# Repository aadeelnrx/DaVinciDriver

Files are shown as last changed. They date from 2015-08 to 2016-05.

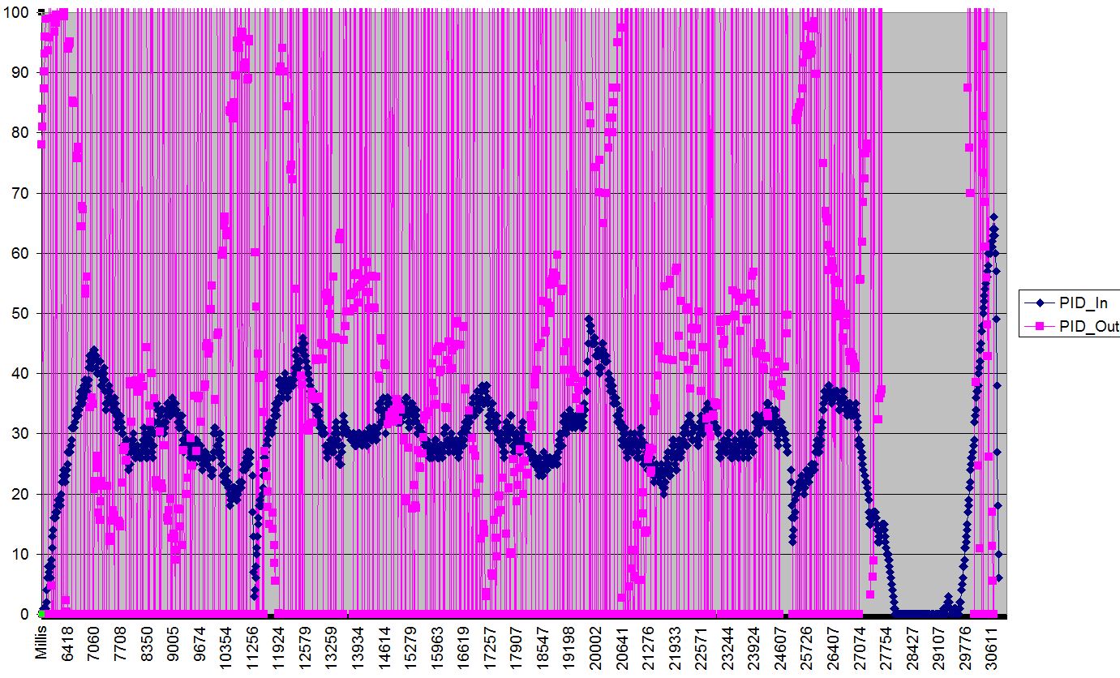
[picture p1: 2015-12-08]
doc/Misc/PID_Measurements/CapturePID_25_10_1.JPG

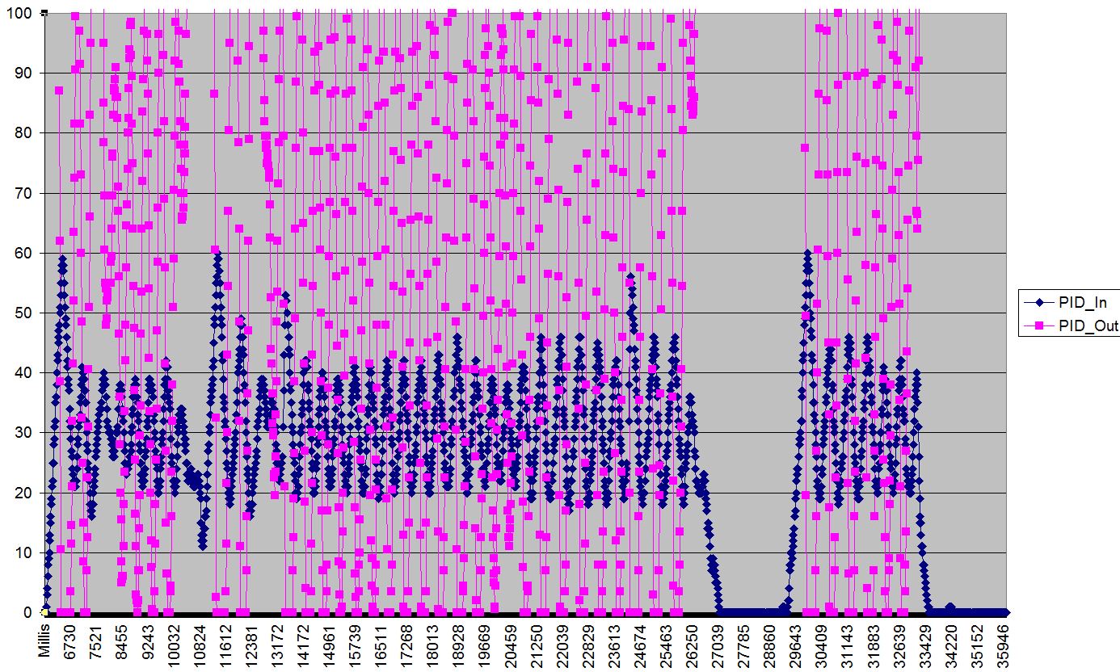
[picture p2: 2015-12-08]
doc/Misc/PID_Measurements/CapturePID_25_100_0.JPG

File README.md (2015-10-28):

# DaVinciDriver

DaVinciDriver is an autonomous slotcar, scale 1:32

It is based on:
* Scalextric chassis W8835 Mercedes CLK (spare part for the Challenger)
* [Teensy 3.1](http://pjrc.com/teensy/teensy31.html)
* [Bosch BNO055 IMU](http://www.bosch-sensortec.com/en/homepage/products_3/sensor_hubs/iot_solutions/bno055_1/bno055_4), [Datasheet](http://ae-bst.resource.bosch.com/media/products/dokumente/bno055/BST_BNO055_DS000_12~1.pdf), on [Adafruit breakout board](https://learn.adafruit.com/adafruit-bno055-absolute-orientation-sensor/overview)
* [Toshiba TB6612FNG](http://toshiba.semicon-storage.com/info/docget.jsp?did=10660&prodName=TB6612FNG) H-bridge motor driver on [Pololu breakout board](https://www.pololu.com/product/713)
* [NRF24L01+](https://www.nordicsemi.com/kor/content/download/2726/34069/file/nRF24L01P_Product_Specification_1_0.pdf) radio link for telemetry and remote control
* VS1833 Infrared remote control

Libraries used:
* [dc740's library](https://forum.pjrc.com/threads/24307-nRF24L01-working-in-Teensy-2-0-and-Teensy-3-0) for NRF24L01:  [download](https://forum.pjrc.com/attachment.php?attachmentid=1002&d=1381184909)
* Adafruit libraries for BNO055: [download](https://github.com/adafruit/Adafruit_BNO055/archive/master.zip) and [download](https://github.com/adafruit/Adafruit_Sensor/archive/master.zip) (you need both)
* Greiman's SdFat Library: [download](https://github.com/greiman/SdFat)

License: GPL v2.0

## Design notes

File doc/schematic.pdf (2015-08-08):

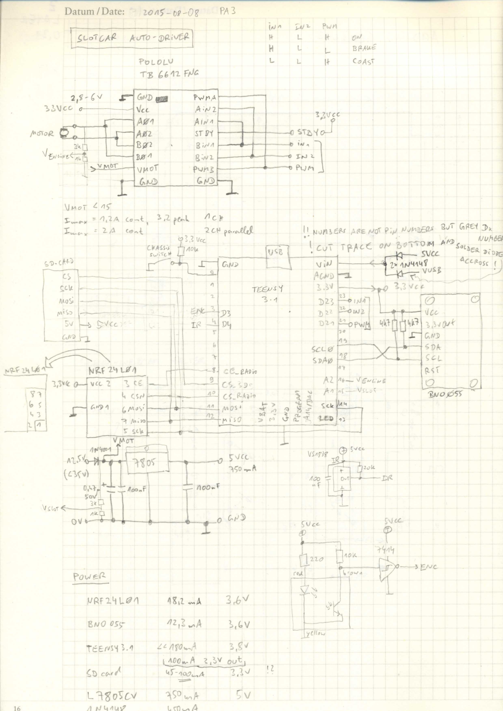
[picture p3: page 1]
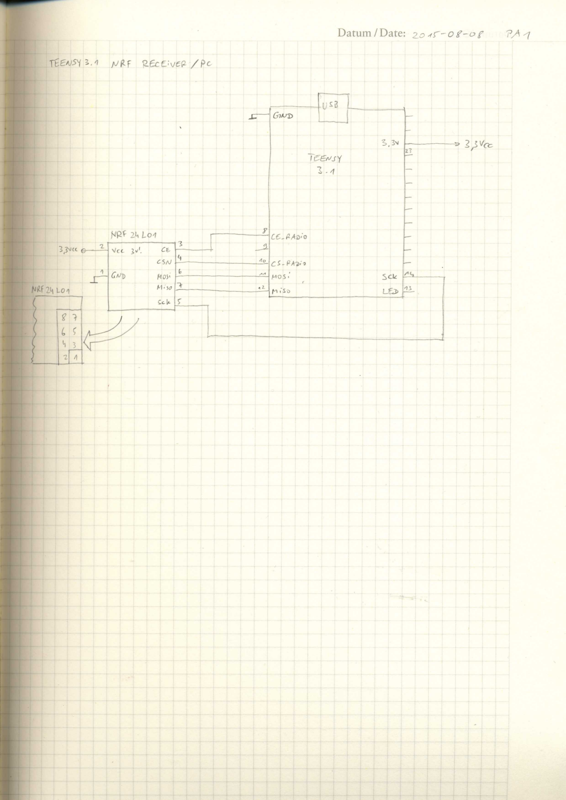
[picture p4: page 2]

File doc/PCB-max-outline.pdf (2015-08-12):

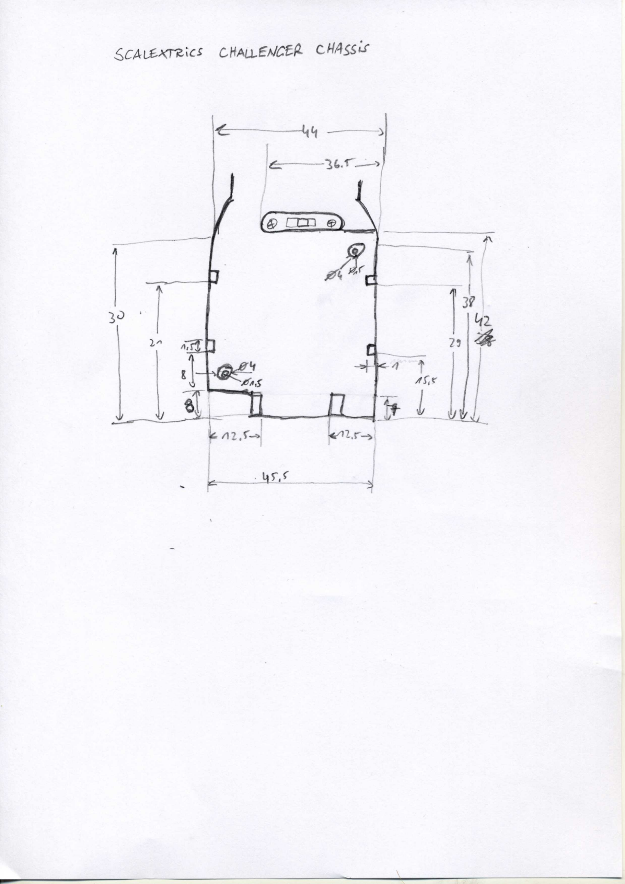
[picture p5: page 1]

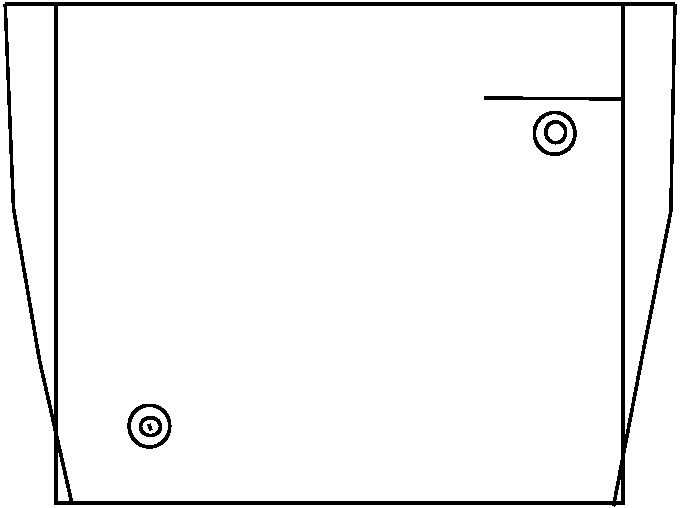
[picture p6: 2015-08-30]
doc/chassis-300dpi3-2.bmp

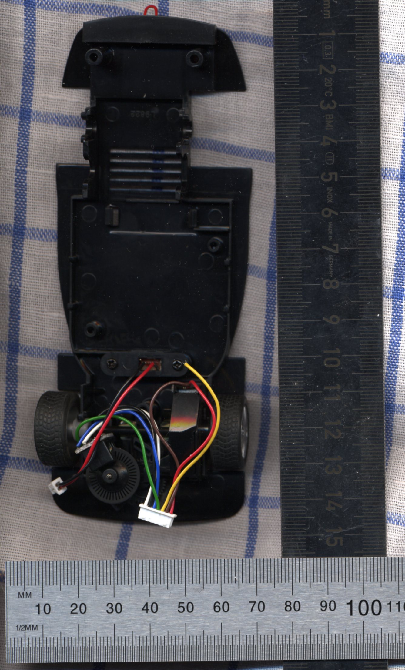
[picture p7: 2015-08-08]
doc/chassis-300dpi.jpg

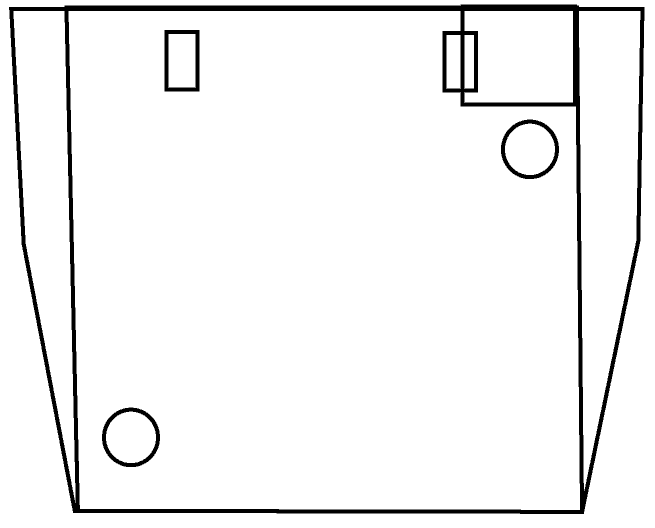
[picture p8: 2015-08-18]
doc/chassis-300dpi2_4bit.bmp

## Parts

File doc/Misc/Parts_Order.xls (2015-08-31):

Part |  | eedala | eedlez | Total | Reichelt | €48.50
Breadboard 640/200 1K2V | Misc |  | 1 | 1 | €2.95 | €2.95
Breadboard 830 SB-2 | Misc |  | 1 | 1 | €4.95 | €4.95
Capacitor 10 uF/16V | Wifi |  | 5 | 5 | €0.17 | €0.85
Capacitor 100 nF/35V | DVD Power |  | 20 | 20 | €0.10 | €2.00
Capacitor 100 uF/25V | DVD Power/Wifi |  | 10 | 10 | €0.04 | €0.40
Capacitor 220000 uF | DVD Power |  | 10 | 10 | €0.79 | €7.90
Diode 1N4004 | DVD Power |  | 5 | 5 | €0.02 | €0.10
Diode 1N4148 | DVD Power |  | 10 | 10 | €0.02 | €0.20
Diode ZF3.3 | DVD Voltage Divider |  | 10 | 10 | €0.04 | €0.40
IC 74HC14 | DVD Wheel Encoder |  | 5 | 5 | €0.23 | €1.15
IR Receiver TSSP4P38??? (VS1838) | DVD Infrared Receiver |  | 5 | 5 | €0.61 | €3.05
LED 3mm Amber (0.18 with R) | DVD Power |  | 5 | 5 | €0.07 | €0.35
LED 3mm Green (0.18 with R) | DVD Power |  | 5 | 5 | €0.06 | €0.30
LED 3mm Green (0.18 with R) | Misc |  | 5 | 5 | €0.06 | €0.30
LED IR 3mm 950nm 65 | IR sender |  | 3 | 3 | €0.36 | €1.08
LED IR 5mm 850nm 65 | IR sender |  | 1 | 1 | €0.62 | €0.62
LM1117T3,3 | Wifi 3,3V |  | 3 | 3 | €1.15 | €3.45
OKI515W36C | DVD Power |  | 2 | 2 | €5.20 | €10.40
Resistor 10K Ohm | DVD Chassis Switch |  | 10 | 10 | €0.05 | €0.49
Resistor 1k Ohm | DVD Voltage Divider |  | 10 | 10 | €0.05 | €0.49
Resistor 220 Ohm | DVD Power + IR Sender |  | 20 | 20 | €0.05 | €0.98
Resistor 5.6K Ohm | DVD Voltage Divider |  | 10 | 10 | €0.05 | €0.49
 |  |  |  |  |  | €0.00
 |  |  |  |  |  | €0.00
 |  |  |  |  |  | €0.00
 |  |  |  |  |  | €0.00

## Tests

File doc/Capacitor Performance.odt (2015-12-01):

Comparison of Capacitor Performance

DaVinci Labs

Technical Report #1

Alex

Rev. B, 2015-11-28

# Revision History

Date | Rev. | Author | Changes
2015-11-28 | A | Alex | Initial version, cap #1-#6
2015-11-28 | B | Alex | Added cap #7, #8, added weight of each capacitor
2015-12-01 | D | Alex | After review: moved elkos and small fixes

# Abstract

The performance of eight capacitors is evaluated. Five capacitors are electrolytic capacitors, while the other three capacitors are SuperCapacitors:

1. Panasonic EEUFC1V102, 1000 μF, 35 V, ESR 0.03 Ω (Reichelt RAD FC 1.000/35)
2. Panasonic EEUFC1C332, 3300 μF, 16 V, ESR 0.02 Ω (Reichelt RAD FC 3.300/16)
3. Panasonic EEUFR1A332B, 3300 μF, 10 V, ESR 0.018 Ω (Reichelt RAD FR 3.300/10)
4. Panasonic EEUFR1A682B, 6800 μF, 10 V, ESR 0.012 Ω (Reichelt RAD FR 6.800/10)
5. Panasonic EEUFC0J103S, 10000 μF, 6.3 V, ESR 0.02 Ω (Reichelt RAD FC10.000/6/3)
6. Panasonic EECS0HD 224, 0.22 F, 5.5 V, ESR < 75 Ω (Reichelt SPK 220.000µF-V)
7. Panasonic EECF5R5U105, 1.0 F, 5.5 V, ESR < 30 Ω (Reichelt SPK 1,0F)
8. Cooper Bussmann PowerStor PA-5R0H474, 0.47 F, 5.0 V, ESR 0.2 Ω (Ebay)
  The picture below shows the different capacitors, with #1 being on the left and #8 on the right hand side.

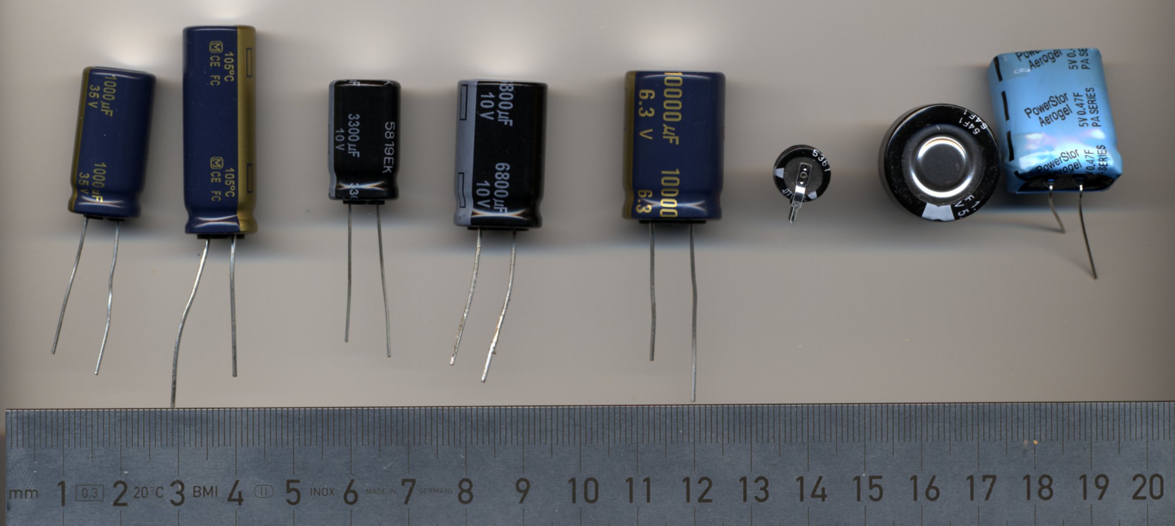
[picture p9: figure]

# Test Setup

To simulate the power used in the DaVinciDriver, which draws up to 80 mA current, the capacitor is first charged with 5V, and then discharged through a resistive load of 55Ω, resulting in a current of ≈100 mA.

Measurements are taken with an AnalogDiscovery PC-based oscilloscope from Digilent Inc.

# Measurements

Table 1 summarizes the measurement results.

# | Capacitor | Nickname | Capacity | ESR | Discharge Time to 3.3V | Weight

1 | EEUFC1V102 | | 1000 μF | 0.03 Ω | 0.026 s | 6 g
2 | EEUFC1C332 | | 3300 μF | 0.02 Ω | 0.092 s | 8 g
3 | EEUFR1A332B | | 3300 μF | 0.018 Ω | 0.092 s | 4 g
4 | EEUFR1A682B | | 6800 μF | 0.012 Ω | 0.1907 s | 8 g
5 | EEUFC0J103S | | 10000 μF | 0.02 Ω | 0.3015 s | 10 g
6 | EECS0HD 224 | Old small GoldCap | 0.22 F | < 75 Ω | 0.005 s | 1 g
7 | EECF5R5U105 | Old big GoldCap | 1.0 F | < 30 Ω | 7.601 s | 8 g
8 | PA-5R0H474 | New blue SuperCap | 0.47 F | 0.2 Ω | 13.282 s | 4 g

# Screenshots

The following screenshots show the discharge curves of the capacitors. Please note that the x-axes have different scales in order to show all relevant data.

## Capacitor #1, EEUFC1V102 : 1000 μF Electrolytic

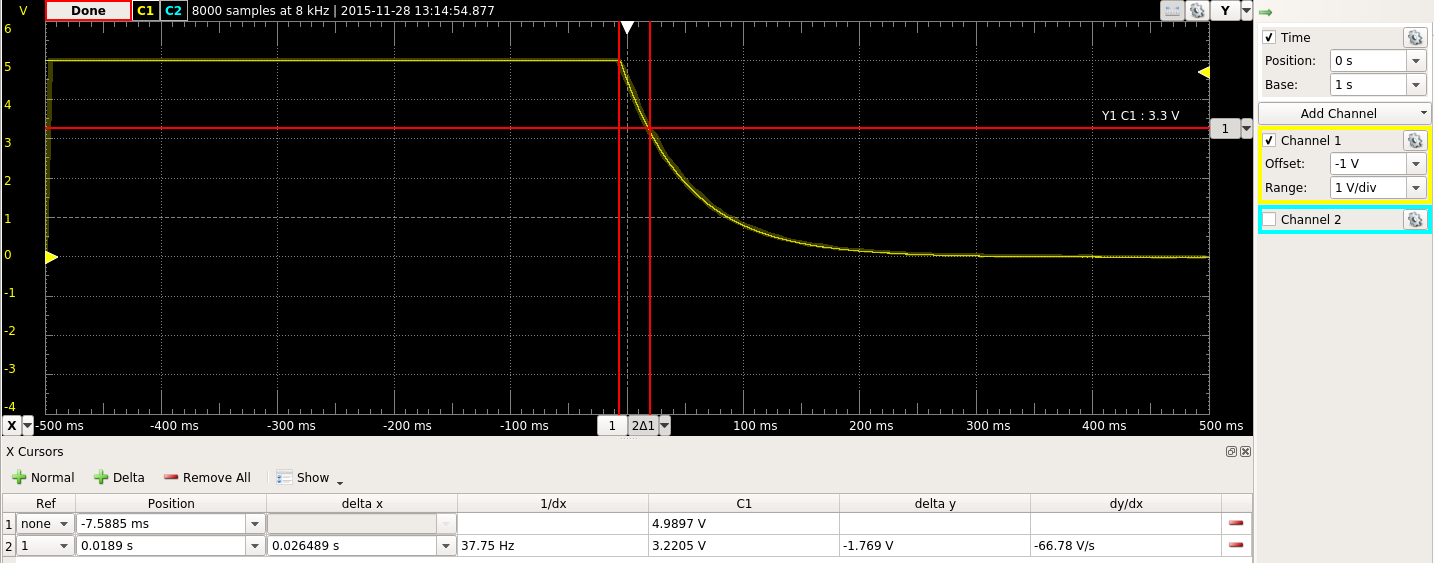
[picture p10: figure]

Discharge time of 0.026 s with a very low ESR. Good performance, but too low capacity for our purposes.

## Capacitor #2, EEUFC1C332: 3300 μF Electrolytic

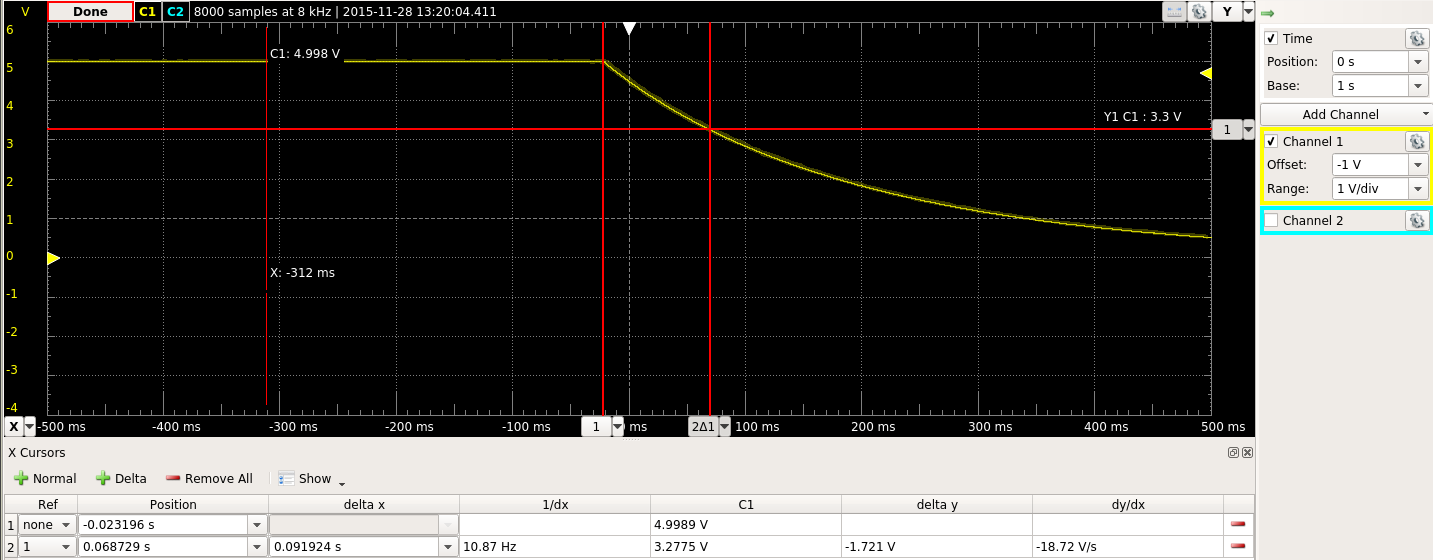
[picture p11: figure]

Discharge time of 0.092 s and low ESR. Same good performance as the smaller electrolytic capacitor #1 with 3x capacity. Still too little capacity for our purposes.

## Capacitor #3, EEUFR1A332B: 3300 μF Electrolytic

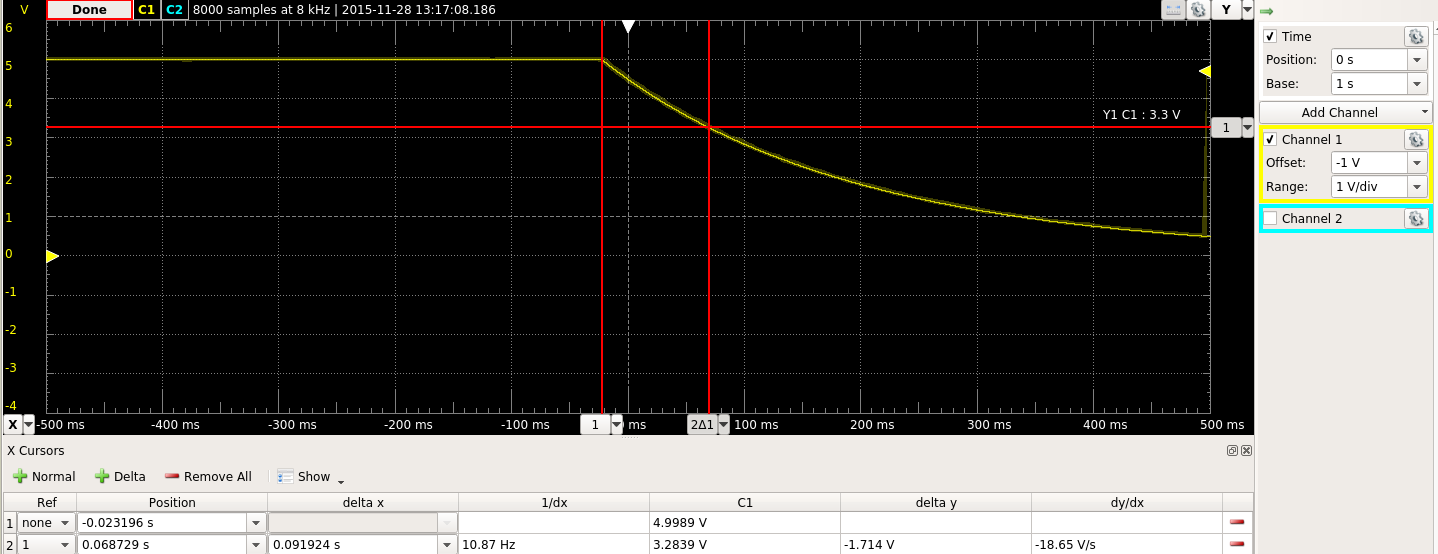
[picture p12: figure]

Essentially the same performance as the previous capacitor, #2, with a nearly identical datasheet. However, this capacitor only has half the physical size of capacitor#2.

## Capacitor #4, EEUFR1A682B: 6800 μF Electrolytic

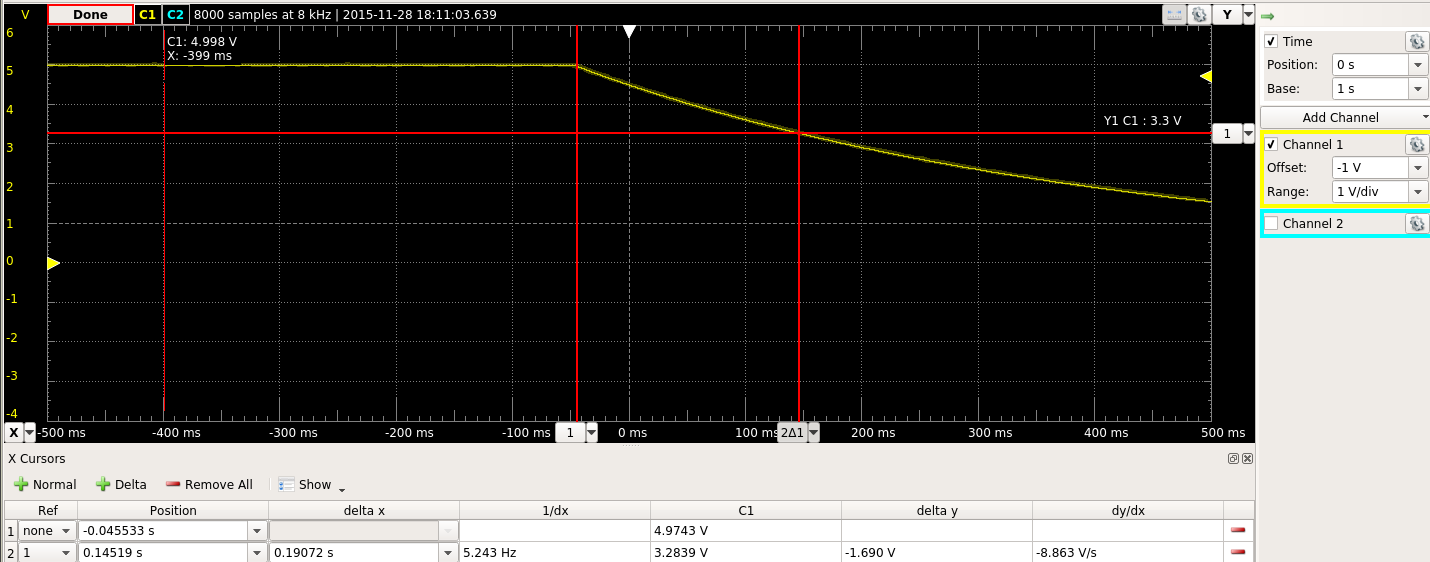
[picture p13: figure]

Standard electrolytic capacitor similar to #1-#3. Its bigger capacity extends the holdover time to 0.19 s, which is still not enough for our purposes.

## Capacitor #5, EEUFC0J103S: 10000 μF Electrolytic

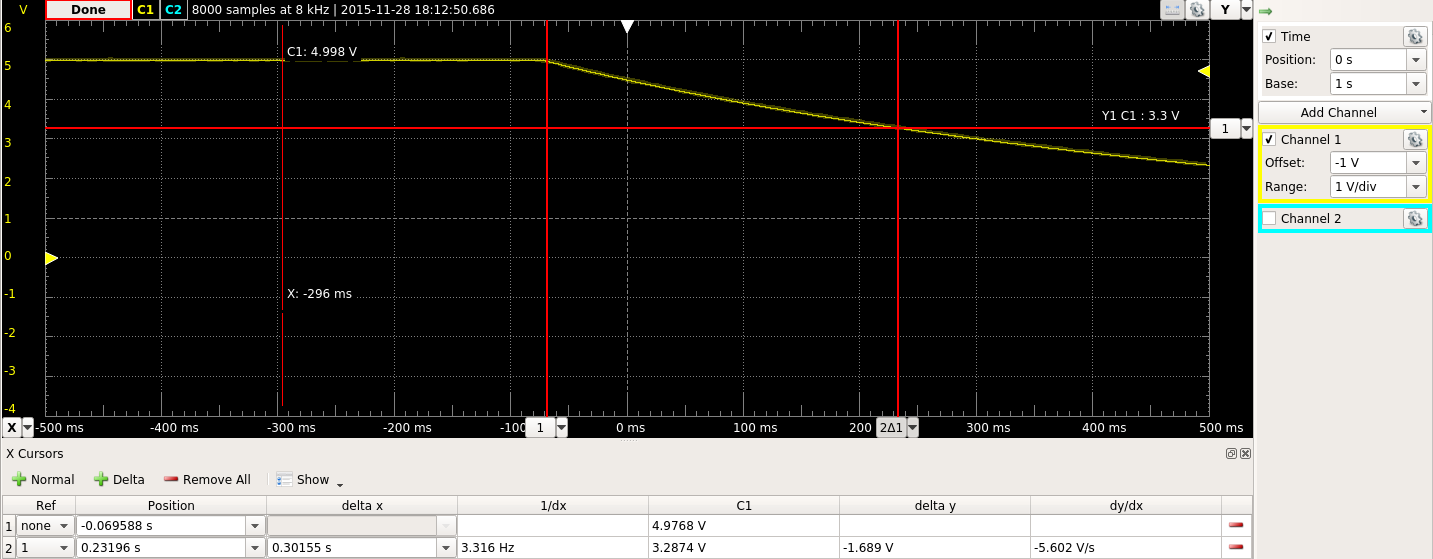
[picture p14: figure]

The highest capacity capacitor with 10000 μF and an expected holdover time of 0.3 s. Not enough, especially considering the weight of this capacitor.

## Capacitor #6, EECS0HD 224: 0.22 F GoldCap

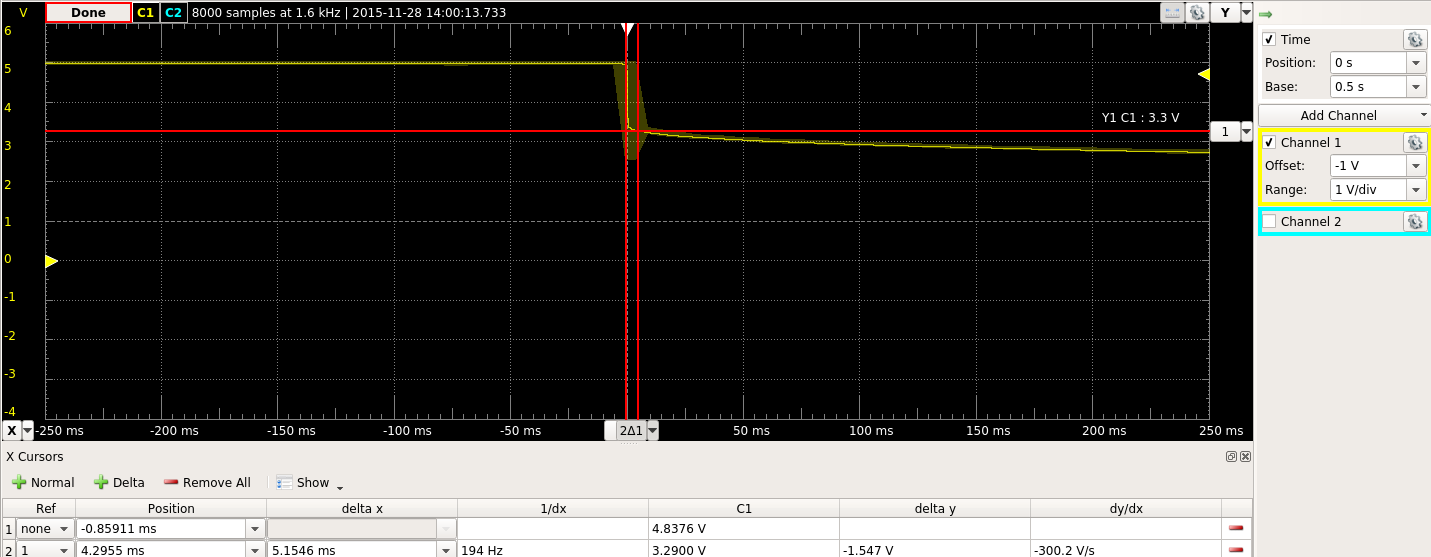
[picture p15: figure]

This is the first capacitor we bought, exhibiting a initial voltage drop of nearly 1.7 V down to 3.3 V which is the minimum acceptable limit. This is caused by a very high ESR value. It is by far the smallest capacitor and according to the data sheet more applicable to backup memory and real-time clocks. It is not intended for milliampere usage scenarios.

## Capacitor #7, EECF5R5U105: 1.0 F GoldCap

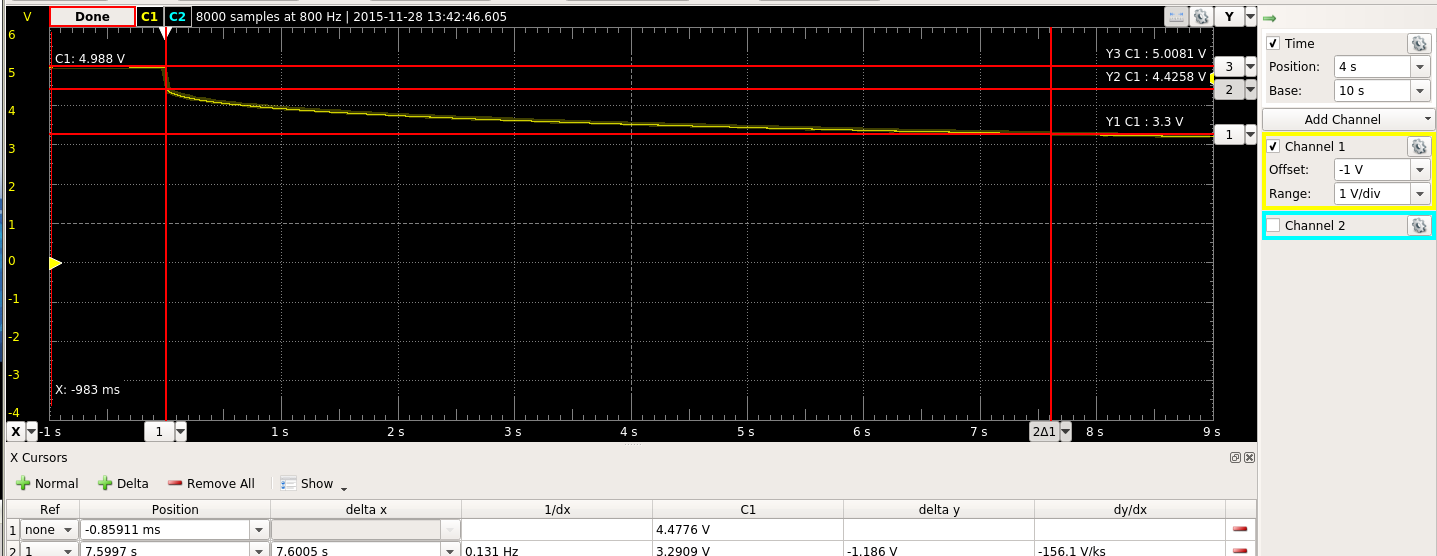
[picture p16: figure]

A much bigger capacitor in physical size than #6 and with 4x its capacity, this capacitor performs better due to its lower ESR value. Compared to the other capacitors the ESR value is still too high and clearly visible in the screenshot above: a step of 0.8 V. Total time to support our car's circuit is acceptable with more than 7 seconds hold-over time.

## Capacitor #8, PA-5R0H474: 0.44 F PowerStor SuperCapacitors

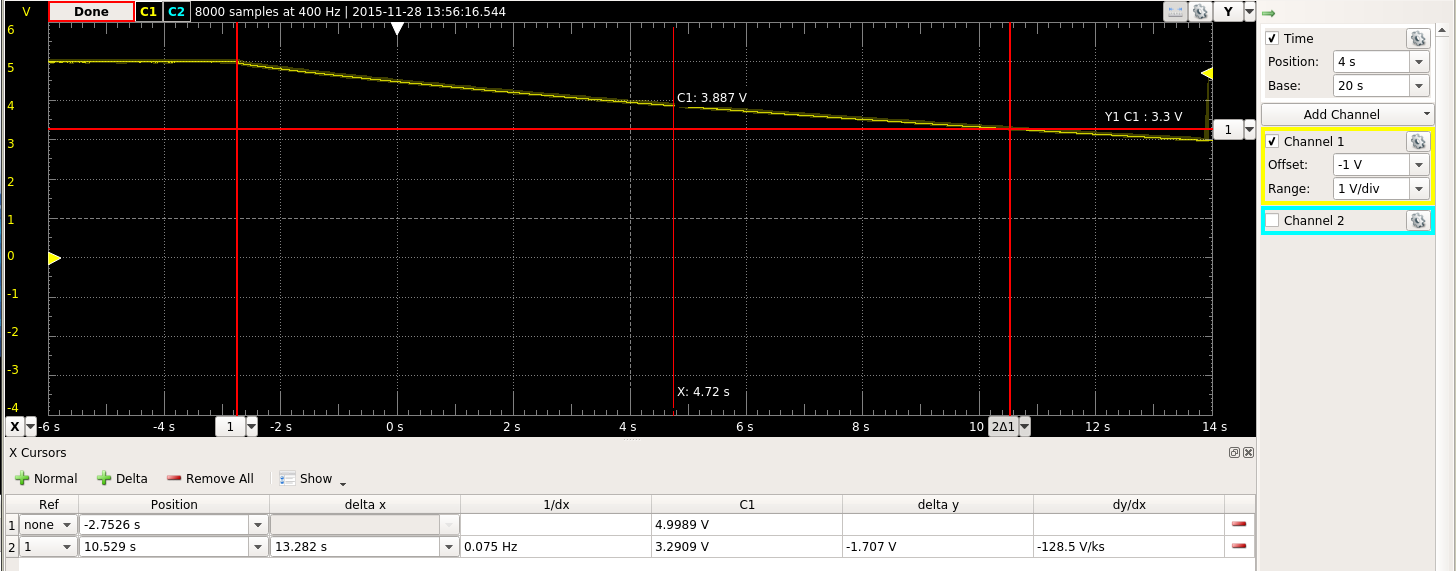
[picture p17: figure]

This capacitor combines the low ESR of the ordinary electrolytic capacitors #1-#5 with the high capacity of the GoldCaps, resulting in an extraordinary holdover time of over 13 seconds. A very good performance considering a price under 1 €, less than the price of the 1.0 F GoldCap #7 which costs 1.60 €.

# Conclusion

Capacitor #8 clearly stands out in this comparison. Longest holdover time at a good price and low weight. The only drawback is its physical size of 24x20x10 mm³.

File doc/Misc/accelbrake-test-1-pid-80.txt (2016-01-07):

-------------------------------------------------
Millis, ExTime, Distance, Speed, Acc_x, Acc_y, TrackVolt
10601, 0, 0, 0, 0.00, 0.00, 426
10621, 0, 0, 0, 0.00, 0.00, 354
10641, 0, 1, 1, 0.00, 0.00, 348
10661, 0, 3, 2, 0.00, 0.00, 339
10681, 0, 6, 3, 0.00, 0.00, 338
10701, 0, 10, 4, 0.00, 0.00, 335
10721, 0, 16, 6, 0.00, 0.00, 333
10741, 0, 22, 6, 0.00, 0.00, 329
10761, 0, 30, 8, 0.00, 0.00, 334
10781, 0, 40, 10, 0.00, 0.00, 331
10801, 0, 51, 11, 0.00, 0.00, 337
10821, 0, 62, 11, 0.00, 0.00, 326
10841, 0, 76, 14, 0.00, 0.00, 331
10861, 0, 91, 15, 0.00, 0.00, 325
10881, 0, 107, 16, 0.00, 0.00, 328
10901, 0, 125, 18, 0.00, 0.00, 331
10921, 0, 144, 19, 0.00, 0.00, 338
10941, 0, 164, 20, 0.00, 0.00, 342
10961, 0, 187, 23, 0.00, 0.00, 341
10981, 0, 209, 22, 0.00, 0.00, 348
11001, 0, 234, 25, 0.00, 0.00, 347
11021, 0, 260, 26, 0.00, 0.00, 346
11041, 0, 286, 26, 0.00, 0.00, 347
11061, 0, 315, 29, 0.00, 0.00, 349
11081, 1, 344, 29, -2.85, 0.33, 351
11101, 1, 373, 29, 0.08, -4.01, 353
11121, 1, 404, 31, -0.57, -0.63, 350
11141, 1, 434, 30, -0.52, -2.75, 351
11161, 1, 467, 33, -0.58, -1.23, 355
11181, 1, 500, 33, -0.74, -3.16, 355
11201, 1, 533, 33, -0.41, 0.32, 356
11221, 1, 567, 34, -1.27, -2.69, 355
11241, 1, 602, 35, 0.24, -0.53, 354
11261, 1, 637, 35, 2.91, -4.31, 365
11281, 1, 673, 36, 6.45, 0.61, 366
11301, 1, 709, 36, 2.03, -2.04, 365
11321, 1, 746, 37, 3.88, -0.42, 366
11341, 1, 782, 36, -0.27, -1.17, 366
11361, 1, 820, 38, -1.17, 1.35, 366
11381, 1, 856, 36, -2.23, -1.40, 364
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

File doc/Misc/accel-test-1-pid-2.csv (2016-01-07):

Millis | ExTime | Distance | Speed | Acc_x | Acc_y | TrackVolt
10805 | 0 | 0 | 0 | 0.00 | 0.00 | 426
10825 | 0 | 0 | 0 | 0.00 | 0.00 | 407
10845 | 0 | 1 | 1 | 0.00 | 0.00 | 413
10865 | 0 | 1 | 0 | 0.00 | 0.00 | 413
10885 | 0 | 1 | 0 | 0.00 | 0.00 | 412
10905 | 0 | 1 | 0 | 0.00 | 0.00 | 410
10925 | 0 | 1 | 0 | 0.00 | 0.00 | 408
10945 | 0 | 1 | 0 | 0.00 | 0.00 | 406
10965 | 0 | 1 | 0 | 0.00 | 0.00 | 404
10985 | 0 | 1 | 0 | 0.00 | 0.00 | 398
11005 | 0 | 1 | 0 | 0.00 | 0.00 | 398
11025 | 0 | 1 | 0 | 0.00 | 0.00 | 394
11045 | 0 | 1 | 0 | 0.00 | 0.00 | 395
11065 | 0 | 1 | 0 | 0.00 | 0.00 | 389
11085 | 0 | 1 | 0 | 0.00 | 0.00 | 388
11105 | 0 | 1 | 0 | 0.00 | 0.00 | 384
11125 | 0 | 1 | 0 | 0.00 | 0.00 | 380
11145 | 0 | 2 | 1 | 0.00 | 0.00 | 367
11165 | 0 | 3 | 1 | 0.00 | 0.00 | 370
11185 | 0 | 5 | 2 | 0.00 | 0.00 | 350
11205 | 0 | 8 | 3 | 0.00 | 0.00 | 362
11225 | 0 | 11 | 3 | 0.00 | 0.00 | 364
11245 | 0 | 16 | 5 | 0.00 | 0.00 | 350
11265 | 0 | 22 | 6 | 0.00 | 0.00 | 353
11285 | 1 | 27 | 5 | -0.58 | -0.19 | 361
11305 | 1 | 34 | 7 | -1.20 | -0.02 | 359
11325 | 1 | 41 | 7 | -0.07 | -0.24 | 364
11345 | 1 | 48 | 7 | -0.36 | -0.87 | 360
11365 | 1 | 56 | 8 | 0.30 | 0.12 | 361
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

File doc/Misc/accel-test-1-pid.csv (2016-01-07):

Millis | ExTime | Distance | Speed | Acc_x | Acc_y | TrackVolt
5815 | 0 | 0 | 0 | 0.00 | 0.00 | 423
5835 | 0 | 0 | 0 | 0.00 | 0.00 | 401
5855 | 0 | 0 | 0 | 0.00 | 0.00 | 401
5875 | 0 | 0 | 0 | 0.00 | 0.00 | 393
5895 | 0 | 0 | 0 | 0.00 | 0.00 | 394
5915 | 0 | 0 | 0 | 0.00 | 0.00 | 395
5935 | 0 | 1 | 1 | 0.00 | 0.00 | 391
5955 | 0 | 1 | 0 | 0.00 | 0.00 | 392
5975 | 0 | 1 | 0 | 0.00 | 0.00 | 382
5995 | 0 | 1 | 0 | 0.00 | 0.00 | 383
6015 | 0 | 1 | 0 | 0.00 | 0.00 | 378
6035 | 0 | 1 | 0 | 0.00 | 0.00 | 379
6055 | 0 | 1 | 0 | 0.00 | 0.00 | 371
6075 | 0 | 1 | 0 | 0.00 | 0.00 | 370
6095 | 0 | 1 | 0 | 0.00 | 0.00 | 361
6115 | 0 | 1 | 0 | 0.00 | 0.00 | 353
6135 | 0 | 1 | 0 | 0.00 | 0.00 | 362
6155 | 0 | 2 | 1 | 0.00 | 0.00 | 361
6175 | 0 | 2 | 0 | 0.00 | 0.00 | 365
6195 | 0 | 4 | 2 | 0.00 | 0.00 | 353
6215 | 0 | 6 | 2 | 0.00 | 0.00 | 353
6235 | 0 | 9 | 3 | 0.00 | 0.00 | 352
6255 | 0 | 13 | 4 | 0.00 | 0.00 | 353
6275 | 0 | 18 | 5 | 0.00 | 0.00 | 352
6295 | 1 | 23 | 5 | 0.00 | 0.00 | 356
6315 | 1 | 28 | 5 | -2.74 | -0.86 | 340
6335 | 1 | 35 | 7 | 1.16 | -1.13 | 340
6355 | 1 | 42 | 7 | -1.92 | -0.67 | 339
6375 | 1 | 49 | 7 | -0.11 | -0.37 | 339
6395 | 1 | 57 | 8 | -1.75 | -0.86 | 341
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

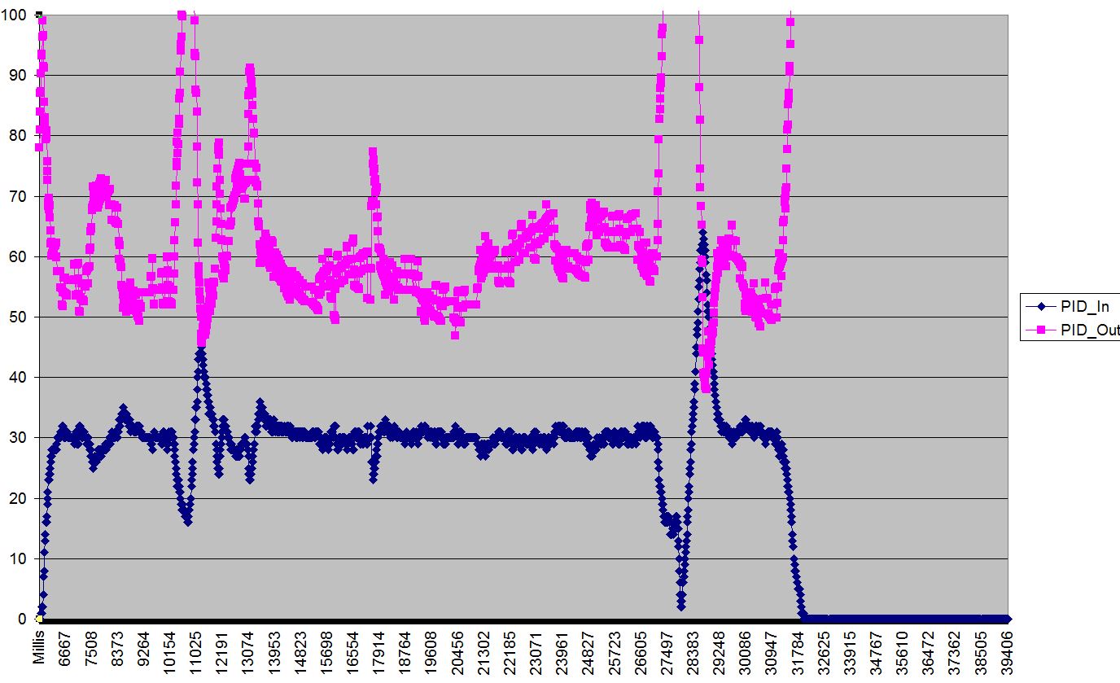
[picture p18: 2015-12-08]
doc/Misc/PID_Measurements/CapturePID_25_10_00001.JPG

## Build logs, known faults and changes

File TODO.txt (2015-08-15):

Open issues:
- connect resistors to i2c bus of bno055?
 =====> I have that on my board, doesn't harm :-)
- we should change all pads to the same style and size (ok, bigger ones
 for the jumpers because the drill hole is also larger).  Pads
 should not be too small (the ones on the resistors are too small)
 because they are harder to manufacture and to solder.  Since we buy
 cheap PCBs I don't know their tolerances, so better use bigger pads.
 I have to find good inner/outer diameters.

???:
- The power on the Schmitt trigger is labelled "-5V" and on the BNO
  it's labelled "-3.3V".  They should be changed to +5V and +3.3V.
  => I see only + no - ?!?!?!
- I would be happier with the 100 nF left of the 7805 and a few 
 uF (10 uF for example) right of the 7805
  => even if spec says 0.1 uF on the left? let's discuss
  => goldcap added on the right
- the BNO footprint is also wider in reality.  Maybe we can leave
 out the "left" pin row, but I'm not sure if that is mechanically
 stable enough.  However, we could fix it mechanically if needed.
  => can be moved as needed

DONE:
- not decided yet where to connect R4 (engine voltage)
 ====> to pin 3 of the Pololu
- all the V+ need to be connected, somehow he didn't do it by himself
 ===> the V+ are all connected, V+ should be the 12V behind the diode.
      It currently is before the diode (as I had it in my earlier
      schematics, but V+ must be behind the diode, otherwise the 
      Pololu and the ADC in the Teensy will get reverse voltage
      when the track power is reversed polarity).
      ===> move V+ behind the diode  
- connect capacitor to nrf24 ?
 =====> good idea, at least 100 nF ceramic
- how to add power/gnd pins to 74hc14
 ====> right-click on the HC14, choose "Invoke", then "PWRN".  Place
       it onto the schematic and connect Vcc and GND.

- I didn't understand the pololu STBY pin, for now I just added a pin/hole (JP10)
 ====> connect to 3.3V to enable the driver all the time
  => connected to PIN 20
- we can change R2 and R4 from 3k to 3.3k, it's easier to buy and a
 safe change as it lowers the voltage on the ADC
  => DONE
- connect goldcap to 7805?
 =====> definitely, otherwise the Teensy might reset while driving
  => DONE
- the diodes at the Teensy (to select between USB and regulator
 voltage) need to be added
  => DONE
- the SPI and I2C connections need to be added to the schematic,
 and the connections from Pololu to Teensy as well
  => DONE, just invisible ;-)
- all free pins should maybe be made available
 =====> with space problems we can still solder to the pads on the
        PCB as I do now on the Lochrasterplatine
- the Pololu footprint needs to be wider (500 mil wide, currently it's
 300 mil)
  => DONE
- the Teensy USB port will collide with the 7805 unless we really
 mount the 7805 horizontally as indicated in the PCB editor.
 But then it sticks out quite a bit.
  => DONE
- the pads for the car speed sensor (what I call encoder) are too
 close on the PCB
  => DONE
- some of the Teensy pins on the underside ("in the middle") are used
 on the PCB.  However, we cannot connect them easily/reliably.
  => DONE

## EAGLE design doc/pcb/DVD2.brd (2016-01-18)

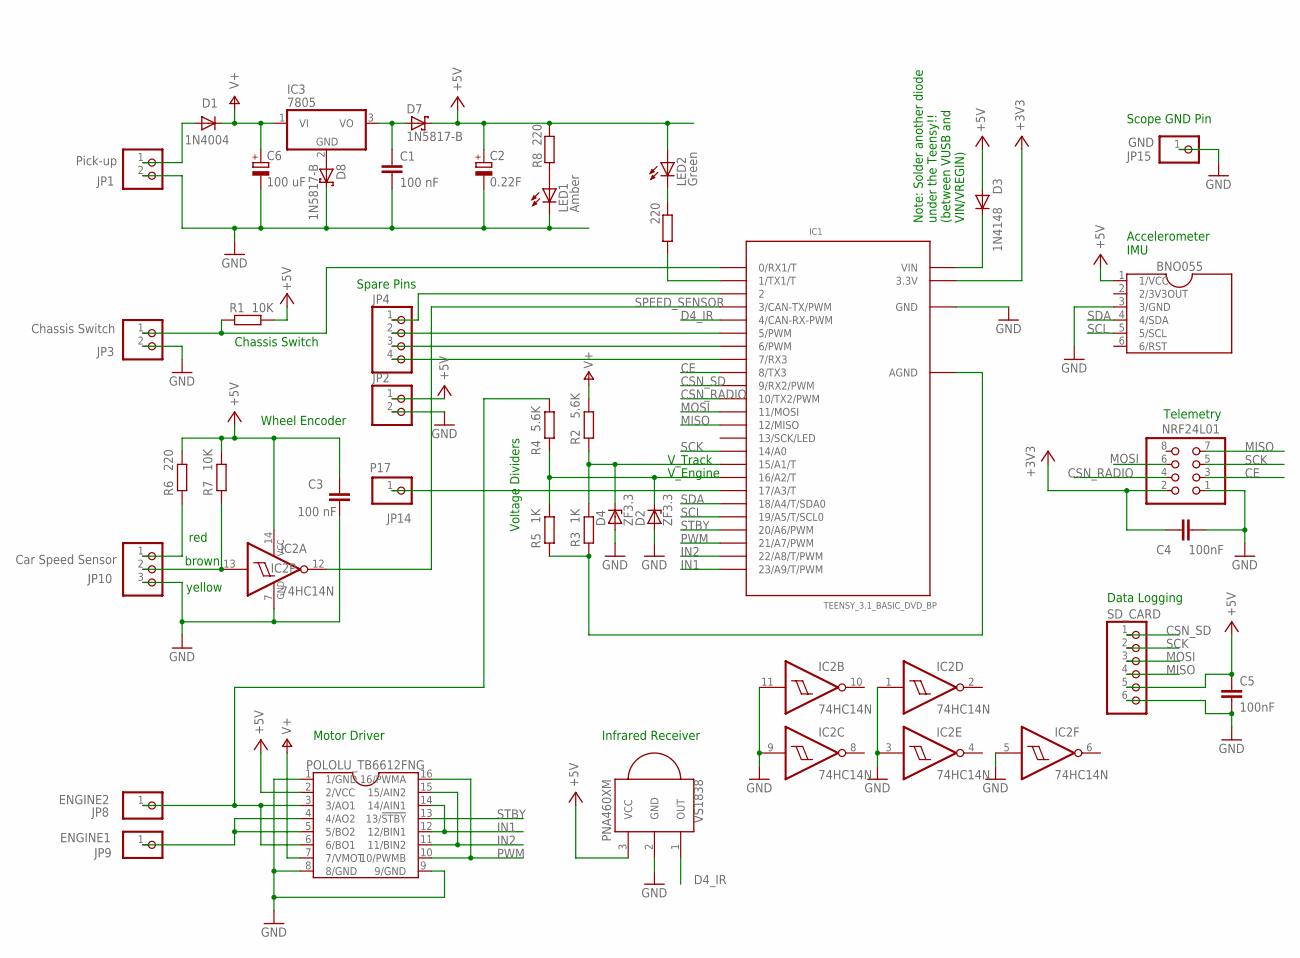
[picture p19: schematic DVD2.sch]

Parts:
BNO055: BNO055_LIGHT; DIL12-6-0
C1, C3: 100 nF; C025-025X050
C2: 0.22F; P128-50
C4: 100nF; C025-025X050
C5: 100nF; C025-024X044
C6: 100 uF; E2,5-6
D1: 1N4004; DO41-10
D2, D4: ZF3.3; ZDIO-7.5
D3: 1N4148; DO41-10
D7, D8: 1N5817-B; DO41-7.6
IC1: TEENSY_3.1_BASIC_DVD_BP; TEENSY_3.1_BASIC_DVD_BIGPADS
IC2: 74HC14N; DIL14
IC3: 7805; TO220V
IC4: POLOLU_TB6612FNG; DIL16WIDE
JP1: Pick-up; 1X02
JP2: PINHD-1X2; 1X02
JP3: Chassis Switch; 1X02
JP4: PINHD-1X4; 1X04
JP8: ENGINE2; 1X01
JP9: ENGINE1; 1X01
JP10: Car Speed Sensor; 1X03
JP14: P17; 1X01
JP15: GND; 1X01
LED1: Amber; LED3MM
LED2: Green; LED3MM
NRF24L01: PINHD-2X4; 2X04
R1, R7: 10K; 0207/10
R2, R4: 5.6K; 0207/10
R3, R5: 1K; 0207/10
R6, R8, R9: 220; 0207/10
SD_CARD: PINHD-1X6; 1X06
VS1838: PNA460XM

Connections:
2/3V3OUT: BNO055.2 (2/3V3OUT)
+3V3: C4.1, IC1.3.3V, NRF24L01.2
+5V: BNO055.1 (1/VCC), C2.+, C3.1, C5.1, D3.A, D7.C, IC2.14 (VCC), IC4.2 (2/VCC), JP2.1, LED2.A, R1.2, R6.2, R7.2, R8.2, SD_CARD.5, VS1838.3 (VCC)
AGND: IC1.AGND, R3.1, R5.1
CE: IC1.8 (8/TX3), NRF24L01.3
CSN_RADIO: IC1.10 (10/TX2/PWM), NRF24L01.4
CSN_SD: IC1.9 (9/RX2/PWM), SD_CARD.1
D4_IR: IC1.4 (4/CAN-RX-PWM), VS1838.1 (OUT)
ENGINE1: IC4.4 (4/AO2), IC4.5 (5/BO2), JP9.1
GND: BNO055.3 (3/GND), C1.2, C2.-, C3.2, C4.2, C5.2, C6.-, D2.A, D4.A, D8.C, IC1.GND, IC2.1 (I), IC2.3 (I), IC2.5 (I), IC2.7 (GND), IC2.9 (I), IC2.11 (I), IC4.1 (1/GND), IC4.8 (8/GND), IC4.9 (9/GND), JP1.2, JP2.2, JP3.2, JP10.3, JP15.1, LED1.K (C), NRF24L01.1, SD_CARD.6, VS1838.2 (GND)
IN1: IC1.23/A9 (23/A9/T/PWM), IC4.12 (12/BIN1), IC4.14 (14/AIN1)
IN2: IC1.22/A8 (22/A8/T/PWM), IC4.11 (11/BIN2), IC4.15 (15/AIN2)
JP8: IC4.3 (3/AO1), IC4.6 (6/BO1), JP8.1, R4.2
MISO: IC1.12 (12/MISO), NRF24L01.7, SD_CARD.4
MOSI: IC1.11 (11/MOSI), NRF24L01.6, SD_CARD.3
unnamed: D3.C, IC1.VIN
unnamed: JP10.1, R6.1
unnamed: IC1.5 (5/PWM), JP4.2
unnamed: LED2.K (C), R9.2
unnamed: C1.1, D7.A, IC3.3 (VO)
unnamed: IC1.17/A3 (17/A3/T), JP14.1
unnamed: LED1.A, R8.1
unnamed: D8.A, IC3.2 (GND)
unnamed: D4.C, IC1.15/A1 (15/A1/T), R2.1, R3.2
unnamed: D2.C, IC1.16/A2 (16/A2/T), R4.1, R5.2
unnamed: IC1.0 (0/RX1/T), JP3.1, R1.1
unnamed: IC1.1 (1/TX1/T), R9.1
unnamed: IC1.2, JP4.1
unnamed: IC1.6 (6/PWM), JP4.3
unnamed: IC1.7 (7/RX3), JP4.4
unnamed: IC2.13 (I), JP10.2, R7.1
PICKUP_PLUS: D1.A, JP1.1
PWM: IC1.21/A7 (21/A7/PWM), IC4.10 (10/PWMB), IC4.16 (16/PWMA)
SCK: IC1.14/A0, NRF24L01.5, SD_CARD.2
SCL: BNO055.5 (5/SCL), IC1.19/A5 (19/A5/T/SCL0)
SDA: BNO055.4 (4/SDA), IC1.18/A4 (18/A4/T/SDA0)
SPEED_SENSOR: IC1.3 (3/CAN-TX/PWM), IC2.12 (O)
STBY: IC1.20/A6 (20/A6/PWM), IC4.13 (13/!STBY)
V+: C6.+, D1.C, IC3.1 (VI), IC4.7 (7/VMOT), R2.2

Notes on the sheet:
Voltage Dividers
V_Track
V_Engine
Motor Driver
Wheel Encoder
Chassis Switch
Infrared Receiver
Accelerometer IMU
Telemetry
Data Logging
Note: Solder another diode under the Teensy!! (between VUSB and VIN/VREGIN)
Scope GND Pin
red
brown
yellow
Spare Pins

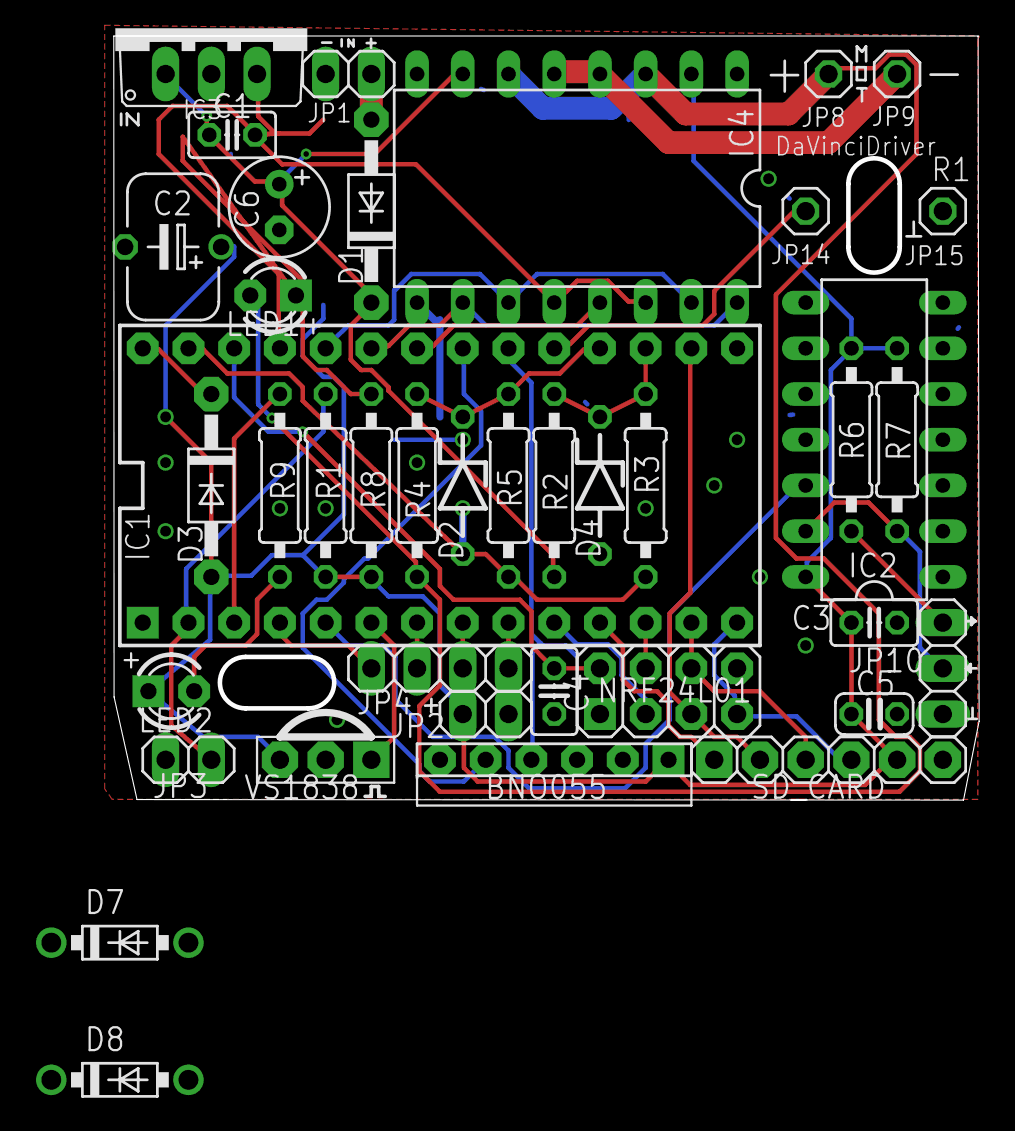
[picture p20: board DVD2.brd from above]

Board: 2 copper layers, 48.1 x 42.5 mm, 40 parts (0 on the bottom side), 38 nets.

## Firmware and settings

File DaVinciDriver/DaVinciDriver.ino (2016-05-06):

/*
 DaVinciDriver

 This program reads the values from the sensor, stores them on SD and transmits them
 via the radio
 
 https://github.com/eedala/DaVinciDriver

 Tools -> Board: Teensy 3.1/3.2
 Tools -> USB Type: Serial
 Tools -> CPU Speed: 72 MHz
 
 */

#include "PinsParameters.h"
#include "datatypes.h"
#include <IRremote.h>
#include "Infrared.h"
#include "Logging.h"
#include "Motor.h"
#include <SdFat.h>
#include <Metro.h>
#include <PID_v1.h>
#include <SPI.h>
#include "Telemetry.h"
#include <RH_NRF24.h>
#include <Wire.h>
#include <Adafruit_Sensor.h>
#include <Adafruit_BNO055.h>
#include "measuring.h"
#include "racing.h"


/*-------------------( Global Variables )-----------------------------------*/
// When to stop the car so that it doesn't drive endlessly during test:
uint32_t stoptime;

// Timers that control the update rates of various things in the main loop:
// Units are milliseconds.
Metro pid_timer = Metro(PID_INTERVAL);
Metro measurement_timer = Metro(LOG_INTERVAL);
Metro racing_timer = Metro(RACING_INTERVAL);

// PID Controller
double PID_setpoint, PID_input, PID_output;
PID PIDcontroller(&PID_input, &PID_output, &PID_setpoint, MOTOR_M_P, MOTOR_M_I, MOTOR_M_D, DIRECT);
// Variables for ASR defining the maximum PWM change
double PID_output_maximized,PID_output_maximized_old = 0;
double PID_max_change = 25;

// Acceleration and orientation
sensors_event_t accel_orient;

// Flag if the BNO055 sensor can be used. 
// The BNO can only be used when it has power applied (5V).
// This is only the case when the car is on the track and gets
// power from there, but not when only the Teensy is powered 
// by USB.  Then the BNO has no power.  Driving the Teensy 
// output pins to the BNO can (and has) locked up the BNO.
bool bno_on = false;
// BNO055 sensor and the data we read from it:
Adafruit_BNO055 bno = Adafruit_BNO055(55);
imu::Vector<3> acceleration;
imu::Vector<3> lacceleration;
imu::Vector<3> gravity;
imu::Vector<3> magnometer;
imu::Vector<3> gyroscope;
imu::Vector<3> euler;
imu::Quaternion quat;

// Infrared remote control receiver
#if IR_ON
IRrecv irrecv(IR_receiver);
decode_results ir_results;
#endif

// Track Voltage Reading and Direction Correction, later is needed due to 360->0 overflow
// not properly working yet
int trackVoltReading;
bool trackPowerPresent;

int dirOverflow = 0;
uint32_t dirReadingOld;

// SD card
#if SD_CARD_ON
File logfile;
// File system object.
SdFat SD;
// Test with reduced SPI speed for breadboards.
// Change spiSpeed to SPI_FULL_SPEED for better performance
// Use SPI_QUARTER_SPEED for even slower SPI bus speed
const uint8_t spiSpeed = SPI_FULL_SPEED;
//const uint8_t spiSpeed = SPI_HALF_SPEED;
//const uint8_t spiSpeed = SPI_QUARTER_SPEED;
#endif

// Telemetry
#if RADIO_ON
  message_t message;
  measurement_t measurement;
  uint32_t seq_no = 0;
  // Set up nRF24L01 radio on SPI bus
  Telemetry telemetry(CE_Radio_PIN, CSN_Radio_PIN);
#endif //RADIO_ON

// Wheel encoder, updated by an interrupt routine
volatile uint32_t speedCounter = 0;
uint32_t speedReading, speedReadingLogged, distance = 0;
uint32_t sp, sp1, sp2, sp3, sp4;  // last 4 values of speedReading

// IR button/action
char irButton[30];

#if RADIO_ON
message_t message;
measurement_t measurement;
char text[26];

// Sequence number for radio messages to detect message loss
uint32_t seq_no;
#endif

//---------------------------------------------------------------
// Car state machine
CAR_STATE state = STARTING_UP;

RACE_STATE race_state = ACCELERATE;

uint32_t startTime;

//---------------------------------------------------------------
// Records for lap detection and lap segment description


// Wanted speed for the different segment types
uint32_t segment_types_speed[] = {20,30,40,60,80,255};
//uint32_t segment_types_speed[] = {25,30,40,60,75,255};

// brake faktor in m/s^2
// needs to be calculated at every different voltage, track surface, etc
double brake_faktor = 3.5;

uint32_t seq_cnt = 0;           // Segment sequence number
uint32_t max_seq_cnt = 1000;    // Maximum number of segments
lap_segment lap[1000];
lap_segment_hist lap_hist[10];
bool measuring = false;         // don't start measuring until BNO055 gives real values 
uint32_t lap_cnt = 0;           // Lap Counter

uint32_t straight_cnt = 0;      // Straight counter
straight_type straight[100];    // Max 100 straights can be stored
bool lap_found = false;         // Indication if Lap recognised
uint32_t finish_position = 0;   // Lap length e.g. start/finish point
uint32_t brake_point = 0;       // brake point before a curve
uint32_t brake_segment = 0;     // segment towards which we are breaking



//------------------------------------------------------------------------
// Interrupt service routine for the wheel encoder:
void countSpeed(){
  speedCounter++;
}

//============================================================================
//============================================================================
// Setup:  Initialize everything
void setup(void)
{
  // Initialise pins
  pinMode(red_LED_PIN,   OUTPUT);
  pinMode(green_LED_PIN, OUTPUT);
  pinMode(speed_PIN,     INPUT);
  // make sure that the default chip select pin is set to
  // output, even if you don't use it:
  pinMode(CSN_CF_PIN,    OUTPUT);
  pinMode(CSN_Radio_PIN, OUTPUT);

  pinMode(CE_Radio_PIN,  OUTPUT);

  // Find out if the car is on the track and gets power from there.
  // Only then drive the BNO, SD-card, and Pololu:
  trackVoltReading = analogRead(track_volt_PIN);
  trackPowerPresent = (trackVoltReading > 100);   // 400 is ca. 10V -> 100 is ca. 2.5V
  
   
  motor_init();
 
  // PID
  PID_input = 0.0;
  PID_setpoint = MOTOR_TARGET_SPEED * PID_INTERVAL / 10 ;
  PIDcontroller.SetSampleTime(PID_INTERVAL);              // set sample time
  PIDcontroller.SetOutputLimits(0, 80);                   // limit the pwm input range for measuring 
  PIDcontroller.SetMode(AUTOMATIC);                       // start PID controller
  sp1 = sp2 = sp3 = sp4 = 0;    
  
  // The default SCK pin is connected to the LED which we use for something else
  // Required for Radio/NRF24L01+ and SD-card
  // !!! Must be before SPI.begin() if that is used !!!
  // In order to make this work, change Line 93 in SdFat/SdSpiTeensy3.cpp from:
  // CORE_PIN13_CONFIG = PORT_PCR_DSE | PORT_PCR_MUX(2);
  // to:
  // CORE_PIN14_CONFIG = PORT_PCR_DSE | PORT_PCR_MUX(2);
  // CORE_PIN13_CONFIG = PORT_PCR_MUX(1);
  SPI.setSCK(SCK_PIN);
  
  digitalWrite(green_LED_PIN, HIGH);

  // initialize the serial communication:
  Serial.begin(115200);

  // Blink to indicate it's going to start:
  for (int i=0; i < 4; i++)
  {
    digitalWrite(green_LED_PIN, HIGH);
    delay(500);
    digitalWrite(green_LED_PIN, LOW);
    delay(500);
  }
  LOG_SERIAL_LN("DaVinciDriver");


  if (trackPowerPresent == true)  {
    bno_on = true;
    // BNO055 IMU initialisation
    // Done here (4 seconds after serial initialisation) so that
    // we can print to serial here.
    LOG_SERIAL_LN("Before bno begin");
    if (!bno.begin())
    {
      Serial.println("bno error");
      //There was a problem detecting the BNO055 ... check your connections
      error("Ooops, no BNO055 detected ... Check your wiring or I2C ADDR!");
    }
    LOG_SERIAL_LN("After bno begin");
  }
  
  Serial.print("BNO is: ");
  Serial.println(bno_on ? "on" : "off (no track voltage?)");
//  while(1);
  
  // last second: fast blinking
  // The BNO055 needs one second to initialise anyway.
  for (int i=0; i < 10; i++)
  {
    digitalWrite(green_LED_PIN, HIGH);
    delay(50);
    digitalWrite(green_LED_PIN, LOW);
    delay(50);
  }
  
  if (bno_on)
  {
    // This has to be done at least one second after bno.begin():
    bno.setExtCrystalUse(true);  
  }

#if WAIT_TO_START
  Serial.println("Type any character to start");
  while (!Serial.available());
#endif //WAIT_TO_START

#if SD_CARD_ON
  // initialize the SD card
  LOG_SERIAL("Initializing SD card...");

  // see if the card is present and can be initialized:
  if (!SD.begin(CSN_CF_PIN,spiSpeed)) {
    LOG_SERIAL_LN("Card failed, or not present");
    // don't do anything more:
    if (SD.card()->errorCode()) {
      LOG_SERIAL_LN(
             "\nSD initialization failed.\n"
             "Do not reformat the card!\n"
             "Is the card correctly inserted?\n"
             "Is chipSelect set to the correct value?\n"
             "Does another SPI device need to be disabled?\n"
             "Is there a wiring/soldering problem?\n");
      LOG_SERIAL("\nerrorCode: ");
      LOG_SERIAL(int(SD.card()->errorCode()));
      LOG_SERIAL(", errorData: ");
      LOG_SERIAL_LN(int(SD.card()->errorData()));
    }
    return;
  }
  LOG_SERIAL_LN("card initialized.");
  
  // create a new file
  char filename[] = "LOGGER00.CSV";
  for (uint8_t i = 0; i < 100; i++) {
    filename[6] = i/10 + '0';
    filename[7] = i%10 + '0';
    if (! SD.exists(filename)) {
      // only open a new file if it doesn't exist
      logfile = SD.open(filename, FILE_WRITE); 
      break;  // leave the loop!
    }
  }
  
  if (! logfile) {
    error("couldnt create file");
  }

  LOG_SERIAL("Logging to: ");
  LOG_SERIAL_LN(filename);
#endif

#if RADIO_ON
  // Initialize all radio related modules
  LOG_SERIAL_LN("Initializing radio...");
  seq_no = 0;
  
  //radio.begin();

  if (! radio.init())
    LOG_SERIAL_LN("init failed");
  // Defaults after init are 2.402 GHz (channel 2), 2Mbps, 0dBm
  if (! radio.setChannel(1))
    LOG_SERIAL_LN("setChannel failed");
  if (! radio.setRF(RH_NRF24::DataRate2Mbps, RH_NRF24::TransmitPower0dBm))
    LOG_SERIAL_LN("setRF failed");   
   
  LOG_SERIAL_LN(F("Radio ready."));
#endif //RADIO_ON

#if IR_ON  
  irrecv.enableIRIn(); // Start the IR receiver
#endif

#if SD_CARD_ON
  logfile.println("Millis,Ex Time,Speed,Distance,Direction,VoltageIn,VoltageEngine,sp1,sp2,sp3,sp4,SR,PID_In,PID_Set,PID_Out,P,I,D,IR,Seq,Pos,l,dir,ST,Wanted_speed,dirChange");    
#endif
#if TEST_LOGGING_ON
  logfile.println("Millis,Ex Time,Ori.x,Ori.y,Ori.z,Acc.x,Acc.y,Acc.z,LAcc.x,LAcc.y,LAcc.z,Grav.x,Grav.y,Grav.z,Mag.x,Mag.y,Mag.z,Gyro.x,Gyro.y,Gyro.z,Euler.x,Euler.y,Euler.z,Quat.w,Quat.x,Quat.y,Quat.z,Speed,Distance,Direction,VoltageIn,VoltageEngine,sp1,sp2,sp3,sp4,SR,PID_In,PID_Set,PID_Out,P,I,D,IR,Seq,Pos,l,dir,ST,Wanted_speed,dirChange");    
#endif
#if ECHO_TO_SERIAL
  LOG_SERIAL_LN("Millis,Ex Time,Ori.x,Ori.y,Ori.z,Acc.x,Acc.y,Acc.z,LAcc.x,LAcc.y,LAcc.z,Grav.x,Grav.y,Grav.z,Mag.x,Mag.y,Mag.z,Gyro.x,Gyro.y,Gyro.z,Euler.x,Euler.y,Euler.z,Quat.w,Quat.x,Quat.y,Quat.z,Speed,Distance,Direction,VoltageIn,VoltageEngine,sp1,sp2,sp3,sp4,SR,PID_In,PID_Set,PID_Out,P,I,D,IR,Seq,Pos,l,dir,ST,Wanted_speed,dirChange");
#endif //ECHO_TO_SERIAL 

  //attempt to write out the header to the file
//  if (logfile.writeError || !logfile.sync()) {
//    error("write header");
//  }
  
// Use different interrupt pin for Teensy & Arduino 
#if defined(CORE_TEENSY)
  attachInterrupt(speed_PIN, countSpeed, CHANGE); 
#else    // Arduino
  //  digitalWrite(speed_PIN, HIGH);
  attachInterrupt(0, countSpeed, CHANGE); 
  // If you want to set the aref to something other than 5v
  //analogReference(EXTERNAL);
#endif

  // Stop the car after some time
  stoptime = millis() + STOP_AFTER_SECONDS * 1000;

  // Reset metro timers so we start at 0
  pid_timer.reset();
  measurement_timer.reset();

  // change car state from initialising to measuring
  state = MEASURING;
}


//====================================================================
//====================================================================
// Main Loop
// Dispatch into the functions that handle each state.  These functions
// return only when the state has changed.
void loop(void)
{  
   switch(state)
   {
        case MEASURING:
           measuring_loop();
           break;
       case MEASURING_FINISHED:
           measuring_finished();
           break;
       case WAIT_FOR_START:
           wait_for_start_loop();
           break;
       case RACING:
           racing_loop();
           break;
       case FINISH:
           finish_loop();
           break;
       default:
           error("Unknown State");
   }
}

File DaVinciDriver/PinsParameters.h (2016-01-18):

#pragma once
//----------------------( Enable Features )------------------------

#define ECHO_TO_SERIAL   1  // echo data to serial port
#define WAIT_TO_START    0  // Wait for serial input in setup()
#define RADIO_ON         0  // Radio transmission
#define IR_ON            0  // IR transmission
#define SD_CARD_ON       1  // Logging to SD card
#define TEST_LOGGING_ON  0  //
#define BNO055_ON        1  // Sensor
#define BNO055_TEST_ON   0  // Extended Sensor reading only valid with BNO055_ON

//----------------------( Declare Constants )------------------------

#define LOG_INTERVAL     10 // mills between logging
#define PID_INTERVAL     10 // mills between PID updates
#define RACING_INTERVAL  10 // mills between PID updates
#define STOP_AFTER_SECONDS 130

//--------------------( Declare Pin Numbers )-------------------------

// LEDs
#define red_LED_PIN 13
#define green_LED_PIN 13

// Sensors
#define speed_PIN 3              // digital 3, interrupt 0
#define track_volt_PIN A1        // analog 1
#define engine_volt_PIN A2       // analog 2

// The SPI pins for CF and Radio
#define CE_Radio_PIN   8
#define CSN_Radio_PIN 10
#define SCK_PIN 14   // SPI bus uses pin 14 instead of pin 13 (used for LED)
#define CSN_CF_PIN 9

// The IR receiver digital pin
#define IR_receiver 4

// Motor driver interface (PWM on these pins uses timer 0):
#define motor_In1_PIN 23
#define motor_In2_PIN 22
#define motor_PWM_PIN 21
#define motor_STBY_PIN 20

// Motor PWM Frequency
// To calculate you need R and L of the motor.
// First the time constant (Tc) of the motor:
// Tc = L/R
// In 5*Tc the motor current has risen to 98.2%.
// Choose a minimum duty cycle (dc = 1..100).
// Tmin = 100/dc * 5 * Tc
// PWM_FREQUENCY = 1/Tmin
#define PWM_FREQUENCY  100 // in Hz (guess, I haven't measured R and L)

// Learning Lap(s) PID and speed definition  
#define MOTOR_TARGET_SPEED 25
#define MOTOR_M_P 2.5
#define MOTOR_M_I 5
#define MOTOR_M_D 0.00

// Racing Laps PID definition
#define MOTOR_R_P 10 //30 //20
#define MOTOR_R_I 1
#define MOTOR_R_D 0.00

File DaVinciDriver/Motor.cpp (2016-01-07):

#include "PinsParameters.h"
#include "Motor.h"
#include <Arduino.h>

//------------------------------------------------------------------------
// Initialize motor driver
void motor_init()
{
  pinMode(motor_In1_PIN, OUTPUT);
  pinMode(motor_In2_PIN, OUTPUT);
  pinMode(motor_PWM_PIN, OUTPUT); 
  pinMode(motor_STBY_PIN, OUTPUT); 
  digitalWrite(motor_STBY_PIN, HIGH);
  // Set PWM frequency.  The motor driver can handle 100 kHz max.
  // Setting the frequency on one pin changes it for all other
  // pins on this timer as well (5, 6, 9, 10, 20, 21, 22, 23)
  analogWriteFrequency(motor_In1_PIN, PWM_FREQUENCY);
}

//------------------------------------------------------------------------
// Motor on full speed:
void motor_on()
{
  digitalWrite(motor_In1_PIN, HIGH);
  digitalWrite(motor_In2_PIN, LOW);
  digitalWrite(motor_PWM_PIN, HIGH);
}

//------------------------------------------------------------------------
// Motor on with specified duty cycle:
// Parameters:
//   int dutycycle  -- PWM setting (0..255): 0 = off, 255 = always on
void motor_on_pwm(int dutycycle)
{
  analogWrite(motor_In1_PIN, dutycycle);
  digitalWrite(motor_In2_PIN, LOW);
  digitalWrite(motor_PWM_PIN, HIGH);
}

//------------------------------------------------------------------------
// Motor off, coasting:
void motor_off_coast()
{
  analogWrite(motor_In1_PIN, 0);
  digitalWrite(motor_In1_PIN, LOW);
  digitalWrite(motor_In2_PIN, LOW);
  digitalWrite(motor_PWM_PIN, HIGH);
}

//------------------------------------------------------------------------
// Motor off, hard brake:
void motor_off_brake()
{
  digitalWrite(motor_In1_PIN, HIGH);
  digitalWrite(motor_In2_PIN, LOW);
  digitalWrite(motor_PWM_PIN, LOW);
}

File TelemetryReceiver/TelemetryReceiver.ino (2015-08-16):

/*
 Receiver for Telemetry data sent by the DaVinciDriver via radio
 Prints the received data on the serial port.
 Every time a message is received, the LED on the Teensy flashes.
 
 https://github.com/eedala/DaVinciDriver

 Tools -> Board: Teensy 3.1
 Tools -> USB Type: Serial
 Tools -> CPU Speed: 72 MHz
 
 */

#include <RF24.h>
#include <SPI.h>

// The digital pins that connect to the LEDs
#define red_LED_PIN 13

// The SPI pins for CF and Radio
#define CE_Radio_PIN   8
#define CSN_Radio_PIN 10
#define SCK_PIN 14   // SPI bus uses pin 14 instead of pin 13 (used for LED)

//-------------------------------------------------------------------------
// Structure of our message
struct message_t
{
  uint32_t millis;
  int speed;
  int direction;
  int voltage;
};

//-------------------------------------------------------------------------
RF24 radio(CE_Radio_PIN, CSN_Radio_PIN);

// Radio pipe addresses for the 2 nodes to communicate.
const uint64_t pipes[2] = {0xF0F0F0F0E1LL, 0xF0F0F0F0D2LL};


//-------------------------------------------------------------------------
void setup()
{
  pinMode(red_LED_PIN, OUTPUT);
  digitalWrite(red_LED_PIN, HIGH);  // indicate Power On

  Serial.begin(115200);
  delay(2000);   // Serial over USB needs some time to start
  digitalWrite(red_LED_PIN, LOW);

  Serial.println(F("Telemetry Receiver R1.0"));
  
  // Setup and configure rf radio
  SPI.setSCK(SCK_PIN); // we use an alternate pin for SCK
  radio.begin();

  // optionally, increase the delay between retries & # of retries
  radio.setRetries(15, 15);

  Serial.println(F("Setting up channel"));
  // optionally, reduce the payload size.  seems to
  // improve reliability
  radio.setPayloadSize(sizeof(message_t));
  radio.setChannel(0x4c);
  radio.setPALevel(RF24_PA_MAX);

  // Open pipes to other node for communication
  // Open 'our' pipe for writing
  // Open the 'other' pipe for reading, in position #1 (we can have up to 5 pipes open for reading)
  Serial.println(F("Setting up pipes"));
  radio.openWritingPipe(pipes[1]);
  radio.openReadingPipe(1, pipes[0]);

  // Start listening
  Serial.println(F("Start listening"));
  radio.startListening();

  // Dump the configuration of the rf unit for debugging
  //radio.printDetails(); 
  Serial.println(F("Ready."));
  Serial.println(F("millis, speed, direction, trackVoltage"));
}


//---------------------------------------------------------------------------
void loop()
{
  // Check if there is data ready
  if (radio.available())
  {
    digitalWrite(red_LED_PIN, HIGH);  // indicate reception of a message
    
    // Dump the payloads until we've gotten everything
    message_t data;
    bool done = false;
    
    while (!done)
    {
      // Fetch the payload, and see if this was the last one.
      done = radio.read(&data, sizeof(message_t));
      
      // Print it
      //Serial.println(F("Got payload:"));
      Serial.print(data.millis);
      Serial.print(F(", "));
      Serial.print(data.speed);
      Serial.print(F(", "));
      Serial.print(data.direction);
      Serial.print(F(", "));
      Serial.println(data.voltage);
    }
//Commented out, this can be used later when the telemetry station (PC)
//wants to send commands to the car      
//    // Delay just a little bit to let the other unit
//    // make the transition to receiver
//    delay(20);  
//
//    // First, stop listening so we can talk
//    radio.stopListening();
//    
//    // Send the final one back.
//    radio.write( &got_time, sizeof(unsigned long) );
//    
//    // Now, resume listening so we catch the next packets.
//    radio.startListening();
 
    digitalWrite(red_LED_PIN, LOW);
  }
}

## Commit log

2015-08-08 added schematic and chassis scan
2015-08-09 Modified IR switch
    Added translateIR and IR variables to IR_ON switch
2015-08-10 Added PCB first design
    [DVD.brd, DVD.sch]
2015-08-10 Cleanup and some first radio changes
    Radio is not working yet.
    - changed radio message struct to reflect the data types we have
    - move SPI's SCK pin to the one we use
    Cleanup:
    - renamed pin names to more uniform format
    - error() function now with "const" to fix a warning
    - disable interrupts when reading/resetting speedCounter
    [DaVinciDriver.ino]
2015-08-10 Radio! It works now.
    The telemetry receiver runs on a second Teensy 3.1 that only
    has a NRF24L01+ on the same pins as the DaVinciDriver, but
    no other hardware.
2015-08-11 PCB Schematics update
    Added all known components
    [DVD.sch]
2015-08-11 PCB Board update
    [DVD.brd]
2015-08-12 Updated PCB
    Moved V+
    Added Capacitors
    Added power to schmitt trigger
    [DVD.sch]
2015-08-12 PCB Update
    Added connection from Pololu to voltage measuring resistors
    [DVD.sch]
2015-08-12 Added PCB maximum outline
    The measurements are the inside of the chassis, i.e. the maximum
    PCB outline.
2015-08-14 Fixed wheel encoder for Teensy
    [DaVinciDriver.ino]
2015-08-14 Added engine temperature measurement pin
    [DVD.sch]
2015-08-14 Added temperature, standby and engine voltage pins and variables
2015-08-15 Cleaned up parts of TODO list
    - declared STBY as ouput
    - added Diodes in Teensy input
    - ...
    [DVD.sch]
2015-08-15 Exchanged Teensy footprint PCB
    [DVD.sch]
2015-08-15 Fixed Pololu/BNO055/Teensy footprint
    [DVD.brd, DVD.sch]
2015-08-16 Fixed DR violations & added Copper Pour GND
    [DVD.brd]
2015-08-16 PCB removed not connected pins from Teensy
    [DVD.brd, DVD.sch]
2015-08-16 Created DVD.lbr for not existing parts and included them on PCB
    [DVD.brd, DVD.sch]
2015-08-16 Cleanup of Telemetry receiver, indicate activity
    The LED goes on for 2 sec during setup() and then
    flashes every time a message was received.
    Also some cleanup.
2015-08-16 PCB contacted Analog meas with AGND, removed temp meas
    [DVD.brd, DVD.sch]
2015-08-16 Removed temp reading from Teensy Code
2015-08-16 Fixed small bug (endln)
    [DaVinciDriver.ino]
2015-08-16 added PID loop, increase LOG_INTEVAL
2015-08-17 Cleanup of Schematics
    [DVD.brd, DVD.sch]
2015-08-18 Updated schematic and added groundplate to board of PCB
    [DVD.brd, DVD.sch]
2015-08-18 LED, caps, beauty
    [DVD.sch]
2015-08-19 PCB moved/added capacitors, changed voltage Pololu/BNO055, added pinouts & testpoints
    Only 1 testpoint connected
    [DVD.brd, DVD.sch]
2015-08-19 Replaced axial by radial capacitor
    [DVD.brd, DVD.sch]
2015-08-19 moved TPs, added Zener to ADC input
    [DVD.sch]
2015-08-19 Redid capacitor change
    [DVD.brd, DVD.sch]
2015-08-19 bigger pads for Teensy
    [DVD.brd, DVD.sch]
2015-08-20 Stop motor on error, code cleanup
    I introduced macros for logging to serial, SD-card,
    and both.
    This greatly simplifies and shortens the code.
    If you want to test the macros, copy their definitions
    to a test.c file, add some lines using the macros,
    and run gcc on it like this:
    gcc -E test.c
    The -E option stops after the C-preprocessor (macros,
    ifdef etc.) and shows the result.
    [DaVinciDriver.ino]
2015-08-23 Redrawn Chassis Picture, fixed schematic and created Board
    Please review and give comments
    [DVD.brd, DVD.sch]
2015-08-24 Schematics and PCB Updates
    Schematics:
    - connected all unused gates of 7414 to GND because open
    inputs may draw a lot of current
    - renamed net for PickUp+ so that I can find it in the PCB
    - went through ERC
    PCB:
    - made some tracks wider (power tracks)
    - fixed DRC errors, default ones and also from the PCB
    manufacturer.
    *****NOTE****** 200+ DRC for the solder mask still
    *************** present. I only fixed the ones for
    *************** the tracks and dimensions
    - I had the copper pour up to the board outer dimension
    but that got reset when loading the DRC rules from
    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
    [DVD.brd, DVD.sch]
2015-08-25 PCB updates only
    [DVD.brd]
2015-08-26 PCB: new pads, ripup, partial route
    [DVD.brd, DVD.sch]
2015-08-27 PCB routed
    [DVD.brd]
2015-08-29 PCB updates
    Moved voltage regulator
    Checked that the OKI switching regulator would also fit (it does)
    Moved capacitors around voltage regulator
    Moved motor pins but couldn't make one square
    Made other pin 1 square
    Added more vias to the ground copper pour
    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
    [DVD.brd, DVD.sch]
2015-08-29 PCB and Schematic Updates
    - Added 2-pin jumper for +5V and GND near the 4-pin header with
    spare signal pins
    - Added Langloecher
    - Cut the lower corners of the PCB to make it fit into the car
    [DVD.brd, DVD.sch]
2015-08-30 Silkscreen cleanup, reconnected Vin to 7805
    [DVD.brd, DVD.sch]
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2015-08-31 Added Order List
    [Parts_Order.xls]
2015-09-01 moved Langloecher to other layer and back
    [DVD.brd]
2015-09-23 Added IR Starting Light
    Defined Button PLAY/PAUSE as start/green light
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2015-10-18 Boot time reduced, improved PID loop, radio link
    Booting time is reduced/improved by re-arranging
    the code and removing unnecessary delay() functions.
    The PID loop now updates with 100 Hz (was 10 Hz),
    while the measurement/logging loop is still at 10 Hz.
    This results in a much smoother drive, no pumping.
    PID parameters also tweaked a little.
    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
2015-11-19 Fixed DVD.lbr BNO055
    Fixed pin layout of BNO055
2015-11-19 Created V2 of DVD schematics
    Created V2 of DVD schematics with added diode after voltage regulator
    and fixed BNO055
    [DVD2.sch]
2015-11-23 Added BNO055 switch
    Now it's possible to switch off BNO055
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2015-12-01 Added additional diode to voltage regulator GND connection
    Added diode to get the ref voltage correct
    [DVD2.sch]
2015-12-06 Fixed SD Card storing of Data
    Fixed SD Card storing of Data
    [DaVinciDriver.ino]
2015-12-06 Change PID SetSampleTime from fixed value to PID_INTERVAL value
    [DVD2.brd, LOGGER06.CSV, LOGGER07.CSV]
2015-12-06 Adding Data to analyse
    [LOGGER08.CSV, LOGGER09.CSV, LOGGER11.CSV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]
2015-12-07 Introduced Metro Timer reset
    - Introduced Metro Timer reset
    - put MOTOR_D = 0
    - Included LOGGER14.CSV
    [LOGGER14.CSV]
2015-12-07 Fixed logged Speed
    Added variable speedReadingLogged which is increased at speedReading and
    zeroed at logging
    [LOGGER15.CSV]
2015-12-07 Added pid_timer reset during logging to fix interval overlap
    - Added pid_timer reset during logging to fix interval overlap
    - added corresponding LOGGER16.CSV
    [LOGGER16.CSV]
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2015-12-09 Added capture with 30ms and modified PID values
2015-12-16 Track Recognition & Curve Classification added
    Also measurement intervals put together to 30 ms
2015-12-18 Fixed Fault in stopping the car
    [DaVinciDriver.ino]
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2015-12-18 Modified PID/Logging interval to 10ms
    with reduced measuring/logging, the time needed is around 2-3ms =>
    PID/logging interval can be reduced to 10ms
2015-12-26 Measurements with real Driving and Acceleration/brake test
    [AccelBrake.CSV, Driving.CSV]
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2016-01-07 add more tests, cleanup
    [accel-test-1-pid-2.csv, accel-test-1-pid.csv, accel-test-2-pwm-80-2.csv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]
2016-01-07 Bugfix: motor_brake_coast() did not brake
    [DaVinciDriver.ino]
2016-01-07 Added missing column header, fix outlier values
    [AccelBrake.CSV]
2016-01-10 Fixed direction reading
    Fixed the 360 => 0 and 0 => 360 direction problem
    [DaVinciDriver.ino]
2016-01-18 Only initialize and use BNO when Track Power is present
2016-01-18 Updated DVD2 with extra Diode(s)
    [DVD2.brd, DVD2.sch]
2016-01-30 New variable to indicate if track power is present
2016-02-14 Simulator for the measuring functions.
    It reads the speed and direction from a previously recorded
    CSV file.
    I don't know if GIT stores symbolic links as links or if it
    copies the files.
    Here you can see which files are only links and which are not:
    -rw-r--r-- 1 alex alex2 4101 14 Feb 18:22 Arduino.cpp
    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
2016-05-06 Modified BNO on check
    added text (no track voltage?)
    removed while(1), why was that there?????
